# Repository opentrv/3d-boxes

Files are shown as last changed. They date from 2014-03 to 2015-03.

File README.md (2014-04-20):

opentrv-3d
==========

3D models of boxes for the [OpenTRV](http://opentrv.org.uk/) project.
The models are created in OpenSCAD and come with a `Makefile`. You can
build any of the models either in OpenSCAD using its graphical user
interface or via the command line by using the `make` command.

Building in OpenSCAD
====================

The model files are designed so that they can be built directly inside
OpenSCAD. In order to do this, start OpenSCAD and follow the procedure
below:
- Open the `.scad` file you want to use (`File -> Open` or `CTRL+O`);
- Render it (`Design -> Compile and Render (CGAL)` or `F6`);
- Export as STL (`Design -> Export as STL...`).

Models are split between two areas:
- [main](./src/main/README.md): the main models for the project that define
  boxes for know versions of the electronics;
- [playpen](./src/playpen/README.md): draft models or partial models to try
  out concepts, some of which may eventually graduate to main.

Note that some models in the `playpen` area make use of includes that
are external to this repository. The simplest way to download and install
those includes is to use `make` in the top level directory:

    make includes

Building using the `make` command
=================================

Prerequisites
-------------

In order to build the STL files, you will need the following installed:
- Git,
- Python (to build the dependencies),
- OpenSCAD.

The `Makefile` is designed to run on Linux and has been tested on Ubuntu but
could be adapted to run on other platforms: if you want to adapt it so that it
runs cross-platform, I will gladly accept patches.

Buiding the STL files
---------------------

This is the easy part, just run:

    make

It will then create an `stl` directory that will contain `main` and `playpen`
sub-directories, each containing one `.stl` file per box.

Note that on the first run, you should be connected to the internet as it will
download dependencies needed for some of the boxes.

You can generate the `main` and `playpen` files separately:

    make main
    make playpen

You can also generate a single box if you know which one you want:

    make stl/main/radiator_control-v0p2_rev1.stl

Cleaning up the build products
------------------------------

Cleaning up the build products is simple:

    make clean

Customising the model
=====================

Some parameters of each model can be customised to create a file for display or
for printing, or to take into account imprecisions of some printers. The main
custom options are in the [user-settings.scad](src/main/user-settings.scad)
file and are explained in the file itself.

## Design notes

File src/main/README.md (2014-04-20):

Main models
===========

This area contains the main models for boxes that correspond to known versions
of the OpenTRV PCB. The name of the model reflects that version. For instance,
the radiator control that corresponds to PCB v0p2 Rev 1 is modelled in the file
called `radiator_control-v0p2_rev1.scad`.

Each model has a specific settings file that follows the same convention. For
instance, the settings file for the model above is
`radiator_control-v0p2_rev1-settings.scad`.

In addition, some generic configuration settings can be tuned by changing the
values in the `user-settings.scad` file.

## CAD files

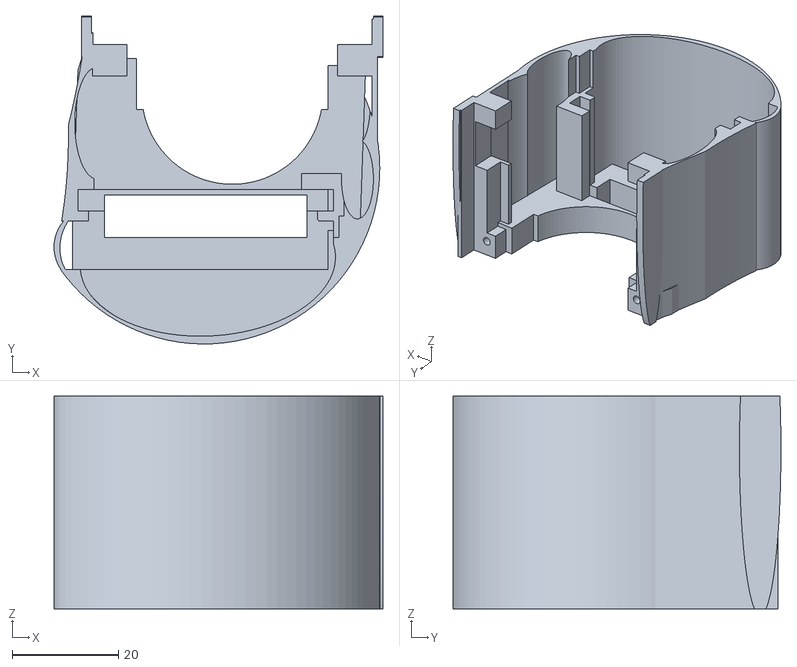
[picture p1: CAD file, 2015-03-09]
src/contrib-stl/valve-cover-8g-bot.stl
61.8 x 61.6 x 40.0

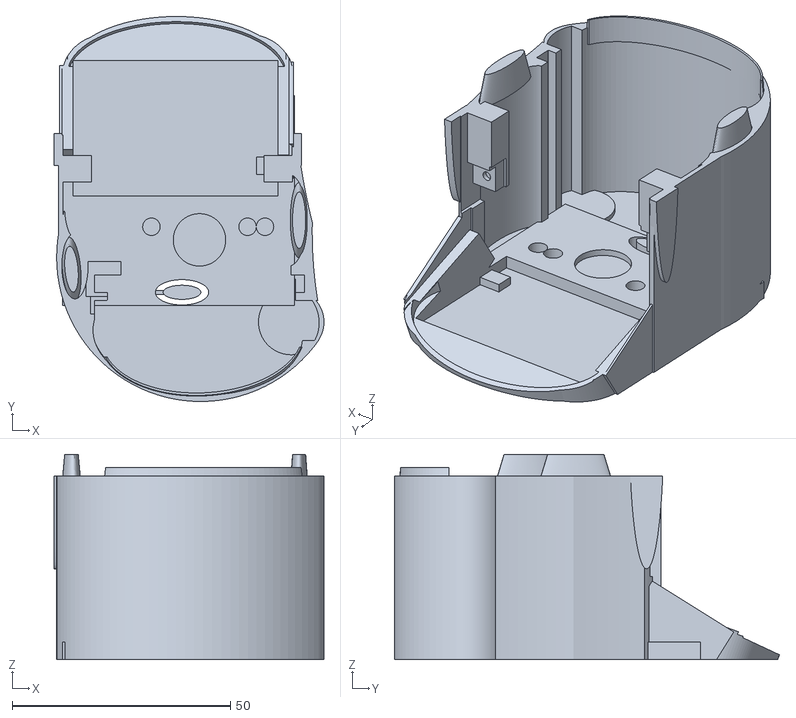
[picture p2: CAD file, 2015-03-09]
src/contrib-stl/valve-cover-8g-top.stl
61.8 x 88.1 x 47.0

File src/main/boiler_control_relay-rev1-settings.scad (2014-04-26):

/*
The OpenTRV project licenses this file to you
under the Apache Licence, Version 2.0 (the "Licence");
you may not use this file except in compliance
with the Licence. You may obtain a copy of the Licence at

http://www.apache.org/licenses/LICENSE-2.0

Unless required by applicable law or agreed to in writing,
software distributed under the Licence is distributed on an
"AS IS" BASIS, WITHOUT WARRANTIES OR CONDITIONS OF ANY
KIND, either express or implied. See the Licence for the
specific language governing permissions and limitations
under the Licence.

Author(s) / Copyright (s): Bruno Girin 2013
*/

include <user-settings.scad>;
include <common-settings.scad>;

/*
PCB board measurements

All measurements and placements are taken such that the version number (V0.09)
is facing the right way up.
*/
/* The basic measurements of the PCB */
pcb_width = 50;
pcb_length = 50;
pcb_thickness = 1.7;

/* Total box height */
box_height = 30;

/* Layer thicknesses */
layer_0_0_thickness = box_layer_thickness;
layer_0_1_thickness = 2 * box_layer_thickness;
layer_0_2_thickness = pcb_thickness;
layer_0_thickness = layer_0_0_thickness + layer_0_1_thickness + layer_0_2_thickness;
layer_1_0_thickness = box_layer_thickness;
layer_1_1_thickness = box_layer_thickness;
layer_1_thickness = layer_1_0_thickness + layer_1_1_thickness;
layer_3_thickness = box_layer_thickness;
layer_2_thickness = box_height - layer_0_thickness - layer_1_thickness - layer_3_thickness;

/* USB connector position */
usb_connector_side = LEFT;
usb_connector_offset = 12;

/* Wire holes */
/* Boiler and power served by same hole */
wire_hole_boiler_power_side = LEFT;
wire_hole_boiler_power_width = 11;
wire_hole_boiler_power_offset = -0.5;

wire_hole_power220_side = RIGHT;
wire_hole_power220_radius = 4;
wire_hole_power220_hoffset = 15;

wire_tie_width = 10;
wire_tie_thickness = 1.5;
wire_tie_iwidth = wire_tie_width - 2 * wire_tie_thickness;
wire_tie_depth = 4;
wire_tie_idepth = wire_tie_depth - wire_tie_thickness;
wire_tie_height = wire_hole_power220_radius;
wire_tie_offset = 2;


/* LED */
led_hole_xoffset = -19.49143125;
led_hole_yoffset = 12.538525;
led_hole_radius = 2.5;

/* Labels */
label_opentrv_chars = ["O", "p", "e", "n", "T", "R", "V"];
label_opentrv_char_count = 7;
label_boiler_chars = ["B", "o", "i", "l", "e", "r"];
label_boiler_char_count = 6;
label_control_chars = ["C", "o", "n", "t", "r", "o", "l"];
label_control_char_count = 7;
label_block_size = 0.75;
label_recess_depth = layer_3_thickness / 2;

/* Nut and bolt recesses */
nut_recess_radius = 6.25 / 2;
nut_recess_height = 2;
bolt_head_recess_height = 1;

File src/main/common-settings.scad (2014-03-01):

/*
The OpenTRV project licenses this file to you
under the Apache Licence, Version 2.0 (the "Licence");
you may not use this file except in compliance
with the Licence. You may obtain a copy of the Licence at

http://www.apache.org/licenses/LICENSE-2.0

Unless required by applicable law or agreed to in writing,
software distributed under the Licence is distributed on an
"AS IS" BASIS, WITHOUT WARRANTIES OR CONDITIONS OF ANY
KIND, either express or implied. See the Licence for the
specific language governing permissions and limitations
under the Licence.

Author(s) / Copyright (s): Bruno Girin 2013
*/

/* General constants */
TOP          = 0;
RIGHT        = 1;
BOTTOM       = 2;
LEFT         = 3;
TOP_RIGHT    = 4;
TOP_LEFT     = 5;
BOTTOM_RIGHT = 6;
BOTTOM_LEFT  = 7;

cylinder_resolution = 90;

/* Settings for the box itself */
box_wall_width = 3;
box_layer_thickness = 3;
box_corner_radius = 2;

/* Small fudge factor to increase holes by in order to take into account
   cooling of the PLA. The actual value can be adjusted in user-settings.scad.
 */
hole_fudge_factor = 0.3 * fudge_ratio;
pcb_fudge_factor = 0.8 * fudge_ratio;

/* Layout settings */
box_layout_spacing = 10;
box_layout_hspacing = box_layout_spacing;
box_layout_vspacing = 2;

/* Lilypad settings */
lilypad_height = 0.3;
lilypad_large_radius = box_layout_hspacing;
lilypad_small_radius = lilypad_large_radius / 2;

/* Cylinder bridge settings */
cylinder_bridge_layer_height = 0.3;
cylinder_bridge_height = cylinder_bridge_layer_height * 3;

/* Generic settings for different types of holes */
pcb_mounting_hole_radius = 1.5; /* Fits an M3 bolt */
pcb_mounting_hole_max_padding = 1;
pcb_mounting_hole_to_edge = 1;
pcb_thickness = 2;

wall_mount_screw_hole_cutout_radius = 1.5;
wall_mount_screw_hole_cutout_large_radius = wall_mount_screw_hole_cutout_radius * 2 + 1;
wall_mount_screw_hole_cutout_thickness = 0.5;
wall_mount_screw_hole_cutout_ratio = 1;

prog_cable_radius = 5;
prog_jack_width = 6.2;
prog_jack_depth = 18;
prog_jack_surround_thickness = 2;

usb_connector_width = 8;
usb_connector_height = 3;
usb_cable_width = 13;
usb_cable_height = 7;

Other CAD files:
src/main/boiler_control_ssr-v0p2_rev1-settings.scad
src/main/radiator_control-v0p2_rev3-settings.scad
src/box_basic.scad
src/main/V1 Box's Bo/bitmap.scad
src/main/V1 Box's Bo/box-common.scad
src/main/V1 Box's Bo/box-v0_2r1-ssr.scad
src/main/V1 Box's Bo/box-v0_2r1.scad
src/main/V1 Box's Bo/box-v0_2r1_Bo_Battery_Box.scad
src/main/V1 Box's Bo/box-v0_2r1_Bo_Hotwater_Cylinder.scad
src/main/V1 Box's Bo/box-v0_2r1_Bo_battery_powered.scad
src/main/V1 Box's Bo/box-v0_2r1_Bo_battery_powered_lid_only.scad
src/main/V1 Box's Bo/settings-v0_2r1-ssr.scad
src/main/V1 Box's Bo/settings-v0_2r1.scad
src/main/V1 Box's Bo/settings-v0_2r1_Bo_Hotwater_Cylinder.scad
src/main/V1 Box's Bo/settings-v0_2r1_Bo_battery_box.scad
src/main/V1 Box's Bo/settings-v0_2r1_Bo_battery_powered.scad
src/main/V1 Box's Bo/settings.scad
src/main/V1 Box's Bo/user-settings.scad
src/main/boiler_control_relay-rev1.scad
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

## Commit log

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2013-10-13 Added support for packages in Makefile and fixed broken layer_0_1_2_merged module
    [box-dd1.scad]
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2013-10-13 Added default scene that shows layers on top of each other
    [box-dd1.scad]
2013-10-13 Generalised the code that creates the holes for the wall mount screws
    [box-common.scad, box-dd1.scad]
2013-10-26 Added cylinder_resolution to ensure rounded shapes are indeed round
    [box-common.scad, settings.scad]
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2013-10-26 Corrected bug in outside hole depth on TOP side
    [box-common.scad]
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2013-10-26 Cleaned up DD1 box and added fudge factor for PCB layer
    [box-dd1.scad]
2013-10-27 Corrected distance between mount hole spacers in sub-board
    [settings-v0_2r1.scad]
2013-10-27 Revert "Corrected distance between mount hole spacers in sub-board" as sub-board PCB was modified to follow SCAD measurements.
    This reverts commit 24297f3ba28309c92a5eaf46e72f53aa53364b4f.
    [settings-v0_2r1.scad]
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2013-11-03 Changed hole fudge factor from 0.1 to 0.2
    [settings.scad]
2013-11-03 Added ventilation slits to left and right sides
    [box-v0_2r1.scad]
2013-11-03 Commented out left ventilation slits until I find why adding them makes layer 3 disappear
    [box-v0_2r1.scad]
2013-11-10 Fixed https://opentrv.atlassian.net/browse/TODO-54
    [settings-v0_2r1.scad]
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2013-11-10 Changed surround padding from 1.5 to 1 as per https://opentrv.atlassian.net/browse/TODO-36
    [settings.scad]
2013-11-10 Increased holes in front of power and boiler terminals as per https://opentrv.atlassian.net/browse/TODO-56
    [box-v0_2r1.scad, settings-v0_2r1.scad]
2013-11-25 De-coupled screw hole and PCB fudge fators, increased both independently as per https://opentrv.atlassian.net/browse/TODO-35
    [box-v0_2r1.scad, settings.scad]
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2013-12-07 Added user settings and made it possible to lay out the layers flat rather than stacked
    [box-common.scad, box-v0_2r1.scad, settings-v0_2r1.scad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]
2013-12-07 Simplified Makefile to reflect new structure in scad files.
    [settings-dd1.scad, settings-v0_09.scad]
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2013-12-08 Made 2nd board struts conical to give them more strength
    [box-v0_2r1.scad]
2013-12-08 Simplfied ventilation slits, added to left side and reduced precision of cylinders for speed
    [box-common.scad, box-v0_2r1.scad, settings.scad]
2013-12-08 Corrected comment
    [user-settings.scad]
2013-12-08 Changed fudge ratio to max fudge by default
    [user-settings.scad]
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2013-12-08 Corrected PCB fudge factor
    [box-SSR.scad]
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2013-12-08 Cleaned up the SSR code and removed unused variables
    [box-SSR.scad, settings-SSR.scad]
2013-12-08 Re-organised the code to differentiate between main and playpen
    [bitmap.scad, box-SSR.scad, box-common.scad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]
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2013-12-08 Added example of bridging upside down nut recesses
    [bridge.scad, sample-upside-down-recess.scad, shapes.scad]
2013-12-08 Added cylinder to cylinder bridges on top of bolt and nut recesses
    [box-common.scad, box-v0_2r1.scad, settings-v0_2r1.scad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]
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2013-12-11 Cut corner of bottom right pillar on layers 1 and 2 to leave space for screw terminal
    [box-v0_2r1.scad]
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2013-12-15 Updated the hole radius for 2nd board to make it dependant on screw size rather than PCB hole size
    [box-v0_2r1.scad, settings-v0_2r1.scad]
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2013-12-15 Changed LED hole radius to fit standard clip
    [box-SSR.scad, settings-SSR.scad]
2013-12-27 Increased width of ventilation slits and number of slits in main box
    [box-SSR.scad, box-common.scad, box-v0_2r1.scad]
2013-12-27 Changed number of slits from 7 to 9 per side
    [box-v0_2r1.scad]
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2013-12-31 Modified ventilation on SSR box and added internal screening.
    [box-SSR.scad, box-common.scad, settings-SSR.scad]
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2014-01-27 Fixed defect TODO-122
    [box-common.scad, settings.scad]
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2014-02-08 Removed top layer rotation and secondary board struts
    [box-v0p2_rev2.scad, settings-v0p2_rev2.scad]
2014-02-08 Removed adjustment to bottom right corner due to components too close to corners in rev1 PCB, now fixed in rev2
    [box-v0p2_rev2.scad]
2014-02-08 Removed recess bridges that are no longer needed
    [box-v0p2_rev2.scad]
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2014-02-08 Removed no longer needed union
    [box-v0p2_rev2.scad]
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2014-02-08 Moved holes for cables and buttons around to fit rev 2
    [box-v0p2_rev2.scad, settings-v0p2_rev2.scad]
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2014-02-08 Moved hole for LED and added hole for LDR based on latest PCB
    [box-v0p2_rev2.scad, settings-v0p2_rev2.scad]
2014-02-09 Flipped 3rd layer to avoide need for bridging
    [box-v0p2_rev2.scad]
2014-02-09 Added fudge factor to potentiometer and Big Red Button holes.
    [box-v0p2_rev2.scad]
2014-02-09 Added TODO to remind myself how to deal with pot
    [settings-v0p2_rev2.scad]
2014-02-10 Generalised the strut shaving code to make it re-usable
    [box-common.scad, box-v0p2_rev1.scad, settings.scad]
2014-02-10 Removed 'magic' constant from lilypads in preparation for general code
    [box-v0p2_rev1.scad]
2014-02-23 Increased depth of slits for Learn buttons to fix TODO-187
    [box-v0p2_rev2.scad, settings-v0p2_rev2.scad]
2014-02-23 Shaved off a bit off the second layer to give space to potentiometer as per TODO-189
    [box-v0p2_rev2.scad, settings-v0p2_rev2.scad]
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2014-02-23 Generalised the lilypad code and updated the rev2 box
    [box-common.scad, box-v0p2_rev2.scad, settings.scad]
2014-02-23 Refactored rev1 boxes and dealt with special cases where n is 1
    [box-common.scad, box-v0p2_rev1-ssr.scad, box-v0p2_rev1.scad]
2014-02-23 Added the ability to print multiple copies of a single layer in an MxN matrix
    [box-v0p2_rev2.scad, user-settings.scad]
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2014-02-24 Shaved bottom left corner on layers 1 and 2 to leave room for the AVR as per TODO-192
    [box-v0p2_rev2.scad]
2014-02-28 Fixed defects TODO-194 and TODO-195
    [box-v0p2_rev2.scad, settings-v0p2_rev2.scad]
2014-02-28 Corrected 1-layer print for flipped layers
    [box-v0p2_rev1.scad, box-v0p2_rev2.scad]
2014-03-01 Separated horizontal from vertical layout spacing and shaved off 1mm from wire hole
    [box-common.scad, box-v0p2_rev2.scad, settings-v0p2_rev2.scad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]
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2014-04-20 Renamed files to ensure consistent and (more) future proof naming convention + updated README accordingly.
    [boiler_control_ssr-v0p1_rev1-settings.scad, boiler_control_ssr-v0p1_rev1.scad, common-settings.scad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]
2014-04-20 Fixed incorrect rename
    [boiler_control_ssr-v0p2_rev1-settings.scad, boiler_control_ssr-v0p2_rev1.scad]
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2014-04-20 Fixed TODO-190
    [radiator_control-v0p2_rev2.scad]
2014-04-24 Updated the vertical distance between layers in stacked mode to be consistent with rev2
    [radiator_control-v0p2_rev1.scad]
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2014-06-07 Fixed TODO-319
    [radiator_control-v0p2_rev2-settings.scad]
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
